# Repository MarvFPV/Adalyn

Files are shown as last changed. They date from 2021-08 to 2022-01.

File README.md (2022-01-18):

# Adalyn

36key QAZ-like handwired keyboard based on the great idea by somepin here on GitHub, check out his repo [here](https://github.com/somepin/qal-handwire)

Currently, the top and bottom are pretty much a friction fit, be aware of that when printing / ordering this case from a fab.

## Required components for handwires

* 36 MX style switches
* 2 2u MX platemount stabs
* 36 Diodes
* a Promicro
* one of ai03's [unified daughterboards](https://github.com/ai03-2725/Unified-Daughterboard)
* a few cables to wire up the matrix
* 4 m3x6mm screws
* 4 m3x8mm countersunk screws 

I personally tend to remove the microUSB connector from the Promicro and solder it directly to a unified daughterboard, that's also why the Promicro cutout may not fit with the USB connector still on the PCB. (I should really write up some documentation on that ^^)

## Required components for the pcb:

- newest pcb based on Atmega32u2

- all necessary components can be found in the bom for jlc/lcsc [here](/PCB/production/smt-assembly) 

## State of PCB:

[Files are ready, prototype not ordered yet]  

- Design moved to an Atmega32u2 as Mcu 

- silkscreen and re-routed, positioned design by [ScatteredDrifter](https://github.com/ScatteredDrifter/Adalyn)

## Render of PCB:

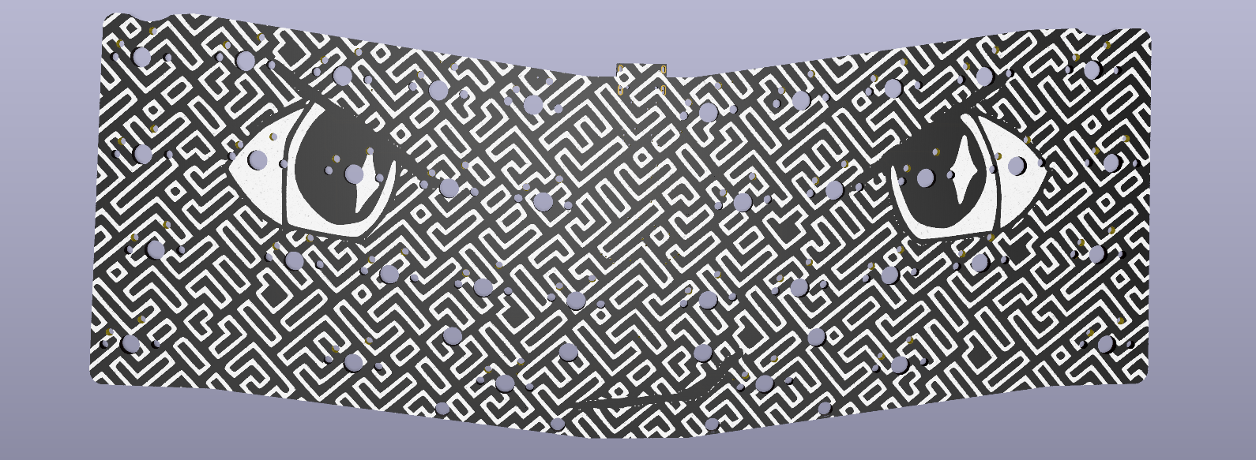
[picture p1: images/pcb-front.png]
frontside


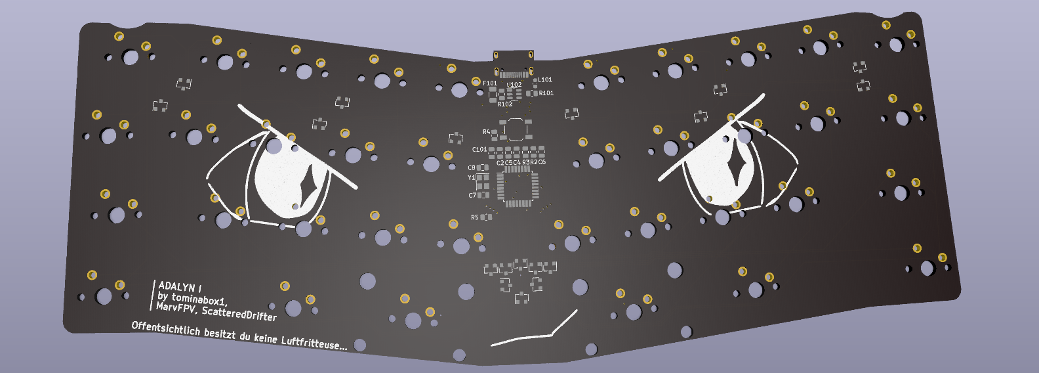
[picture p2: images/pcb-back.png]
backside


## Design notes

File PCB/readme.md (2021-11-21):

# Adalyn PCB
After the development of the handwired Adalyn case, it was clear this great combination needed a formalized pcb. This is that PCB. Designed by tominabox1, the pcb features an ATmega32u4a, USB-C, and ESD protection. The pcb is supported in QMK and VIAL. 

# BOM
The bill of materials is listed below, with LCSC parts where possible. Total unique part count: 14. Total parts: 37. 

| Ref | Qnty | Value | Part | Footprint |
|---|---|---|---|---|
| C1, C2, C4, C101 | 4 | 100nF | C187860  | 0603 |
| C5 | 1 | 10uF | C97885 | 0603 |
| C6 | 1 | 1uF | C302042  | 0603 |
| D101, D102, D103, D104, D105, D106, D107, D108, D109, D110, D111, D112, D113, D114, D115, D116, D117, D118 | 18 | BAV70 | C181110  | SOT-23 |
| F101 | 1 | 700mA | C182438  | 0603 |
| L101 | 1 | 600R@100MHz | C139183  | 0603 |
| R2, R3 | 2 | 22 | C96423 | 0603 |
| R4, R5 | 2 | 10k | C73809 | 0603 |
| R101, R102 | 2 | 5.1k | C415096  | 0603 |
| SW1 | 1 | SW_Push | C589220  | 4.9x4.9 |
| U101 | 1 | ATmega32U4-A | C44854 | TQFP-44_10x10mm_P0.8mm |
| U102 | 1 | PRTR5V0U2X | C2827688 | SOT-143 |
| USB101 | 1 | HRO-TYPE-C-31-M-12 | C165948  | HRO-TYPE-C-31-M-12 |
| Y1 | 1 | 16MHz | C341521  | Crystal:Resonator_SMD_Murata_CSTxExxV-3Pin_3.0x1.1mm_HandSoldering |

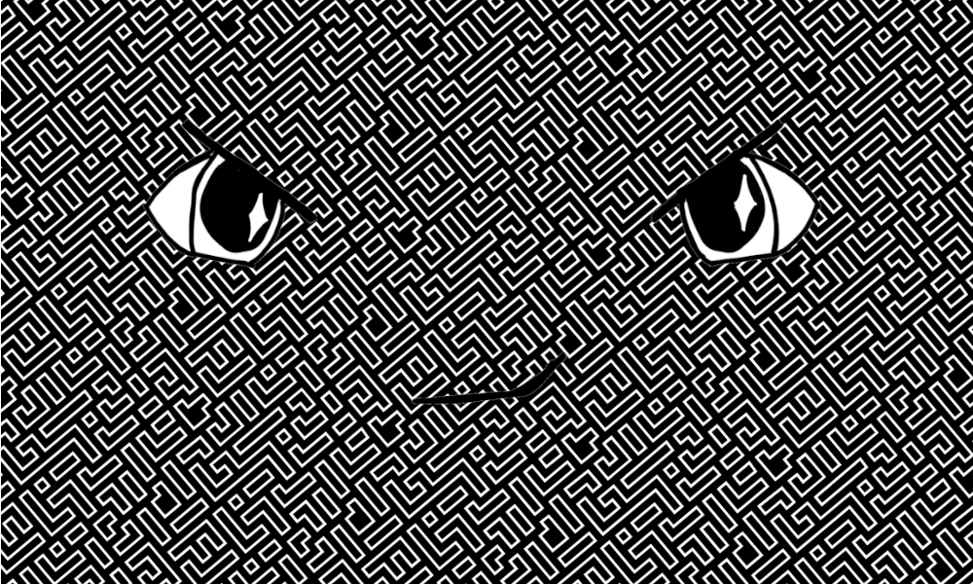
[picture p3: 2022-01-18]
PCB/silkscreen/smirk-pattern-smaller.png

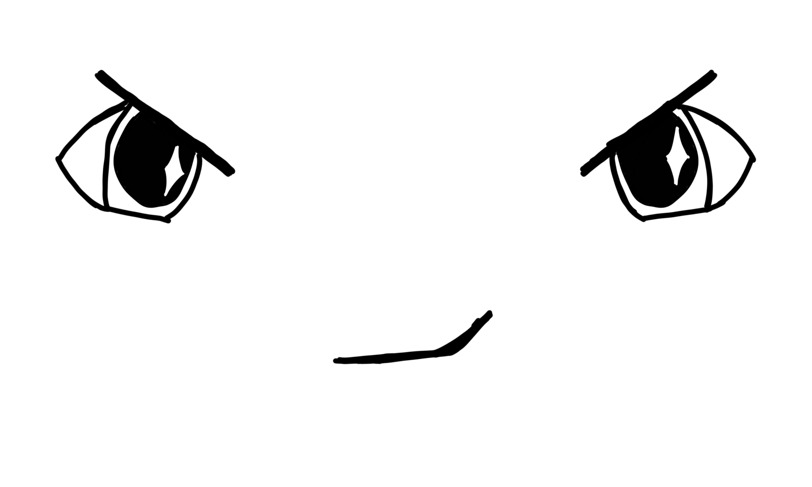
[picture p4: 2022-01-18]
PCB/silkscreen/sketch1642460583686.png

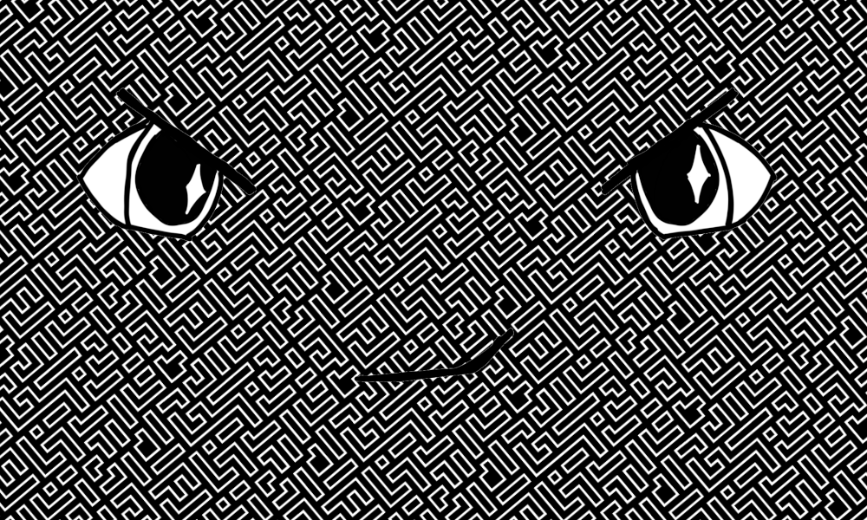
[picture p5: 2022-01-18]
PCB/silkscreen/smirk-pattern-updated.png

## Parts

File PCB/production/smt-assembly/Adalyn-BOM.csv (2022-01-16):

Comment | Designator | Footprint | LCSC
.1uF | C2,C4,C101 | Capacitor_SMD:C_0805_2012Metric | C49678
10uF | C5 | Capacitor_SMD:C_0805_2012Metric | C91245
1uF | C6 | Capacitor_SMD:C_0805_2012Metric | C28323
22pf | C7,C8 | Capacitor_SMD:C_0805_2012Metric | C1804
BAV70 | D101,D102,D103,D104,D105,D106,D107,D108,D109,D110,D111,D112,D113,D114,D115,D116,D117,D118 | Package_TO_SOT_SMD:SOT-23 | C68978
Polyfuse | F101 | Fuse:Fuse_1206_3216Metric | C69688
600R@100MHz | L101 | Inductor_SMD:L_0603_1608Metric
MX-NoLED | MX1,MX2,MX3,MX4,MX5,MX6,MX7,MX8,MX9,MX10,MX11,MX12,MX13,MX15,MX16,MX17,MX18,MX19,MX20,MX21,MX22,MX23,MX24,MX25,MX26,MX27,MX28,MX29,MX30,MX32,MX33,MX34,MX35,MX36,MX37,MX38 | marbastlib-mx:SW_MX_1u
5.1k | R101,R102 | Resistor_SMD:R_0805_2012Metric | C27834
22 | R2,R3 | Resistor_SMD:R_0805_2012Metric | C17561
10k | R4,R5 | Resistor_SMD:R_0805_2012Metric | C17414
SW_Push | SW1 | Keebio-Parts:SW_SPST_TL3342 | C318884
ATmega32U2-AU | U1 | Package_QFP:TQFP-32_7x7mm_P0.8mm | C618733
SRV05-4 | U102 | Package_TO_SOT_SMD:SOT-23-6
HRO-TYPE-C-31-M-12 | USB101 | Type-C:HRO-TYPE-C-31-M-12-Assembly | C165948
Crystal_GND24_Small | Y1 | Crystal:Crystal_SMD_3225-4Pin_3.2x2.5mm | C13738

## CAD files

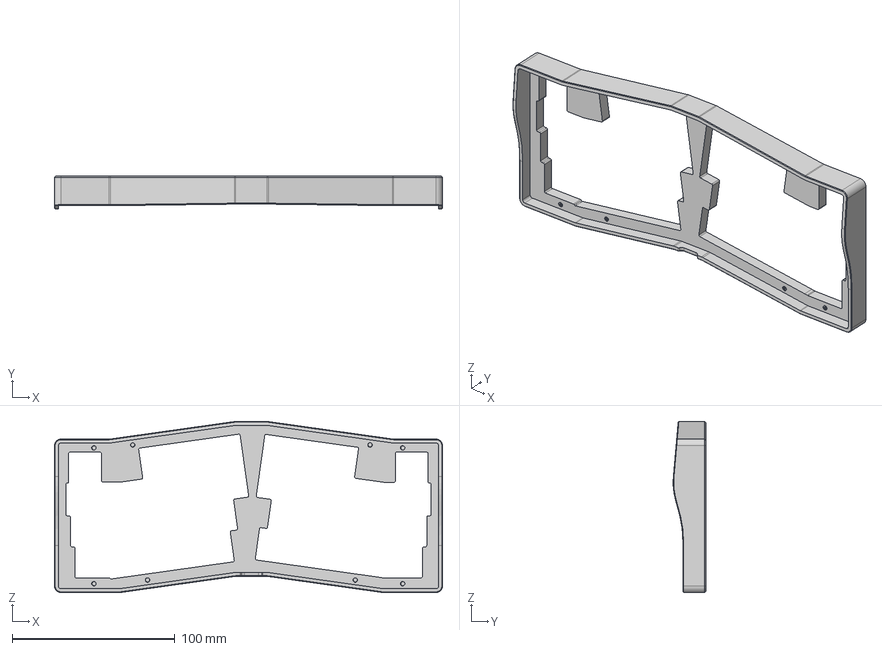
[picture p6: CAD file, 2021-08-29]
STEP/Top.step
238.3 x 20.1 x 105.0 mm

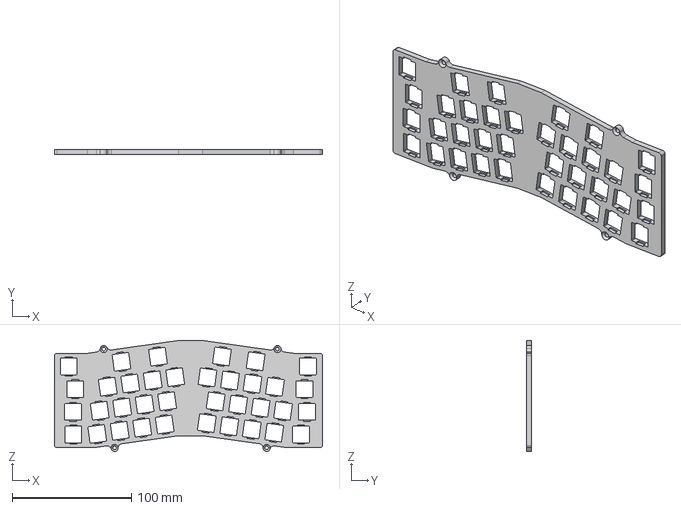
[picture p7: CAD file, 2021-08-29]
STEP/Plate.step
224.8 x 4.00 x 93.1 mm

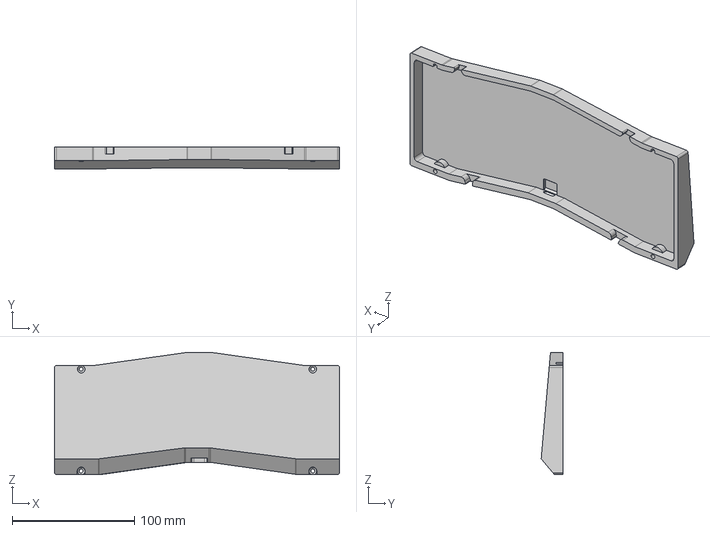
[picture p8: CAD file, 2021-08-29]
STEP/Bottom.step
233.3 x 17.7 x 100.0 mm

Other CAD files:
Adalyn.f3z
STL/Bottom.stl
STL/Plate.stl
STL/Top.stl

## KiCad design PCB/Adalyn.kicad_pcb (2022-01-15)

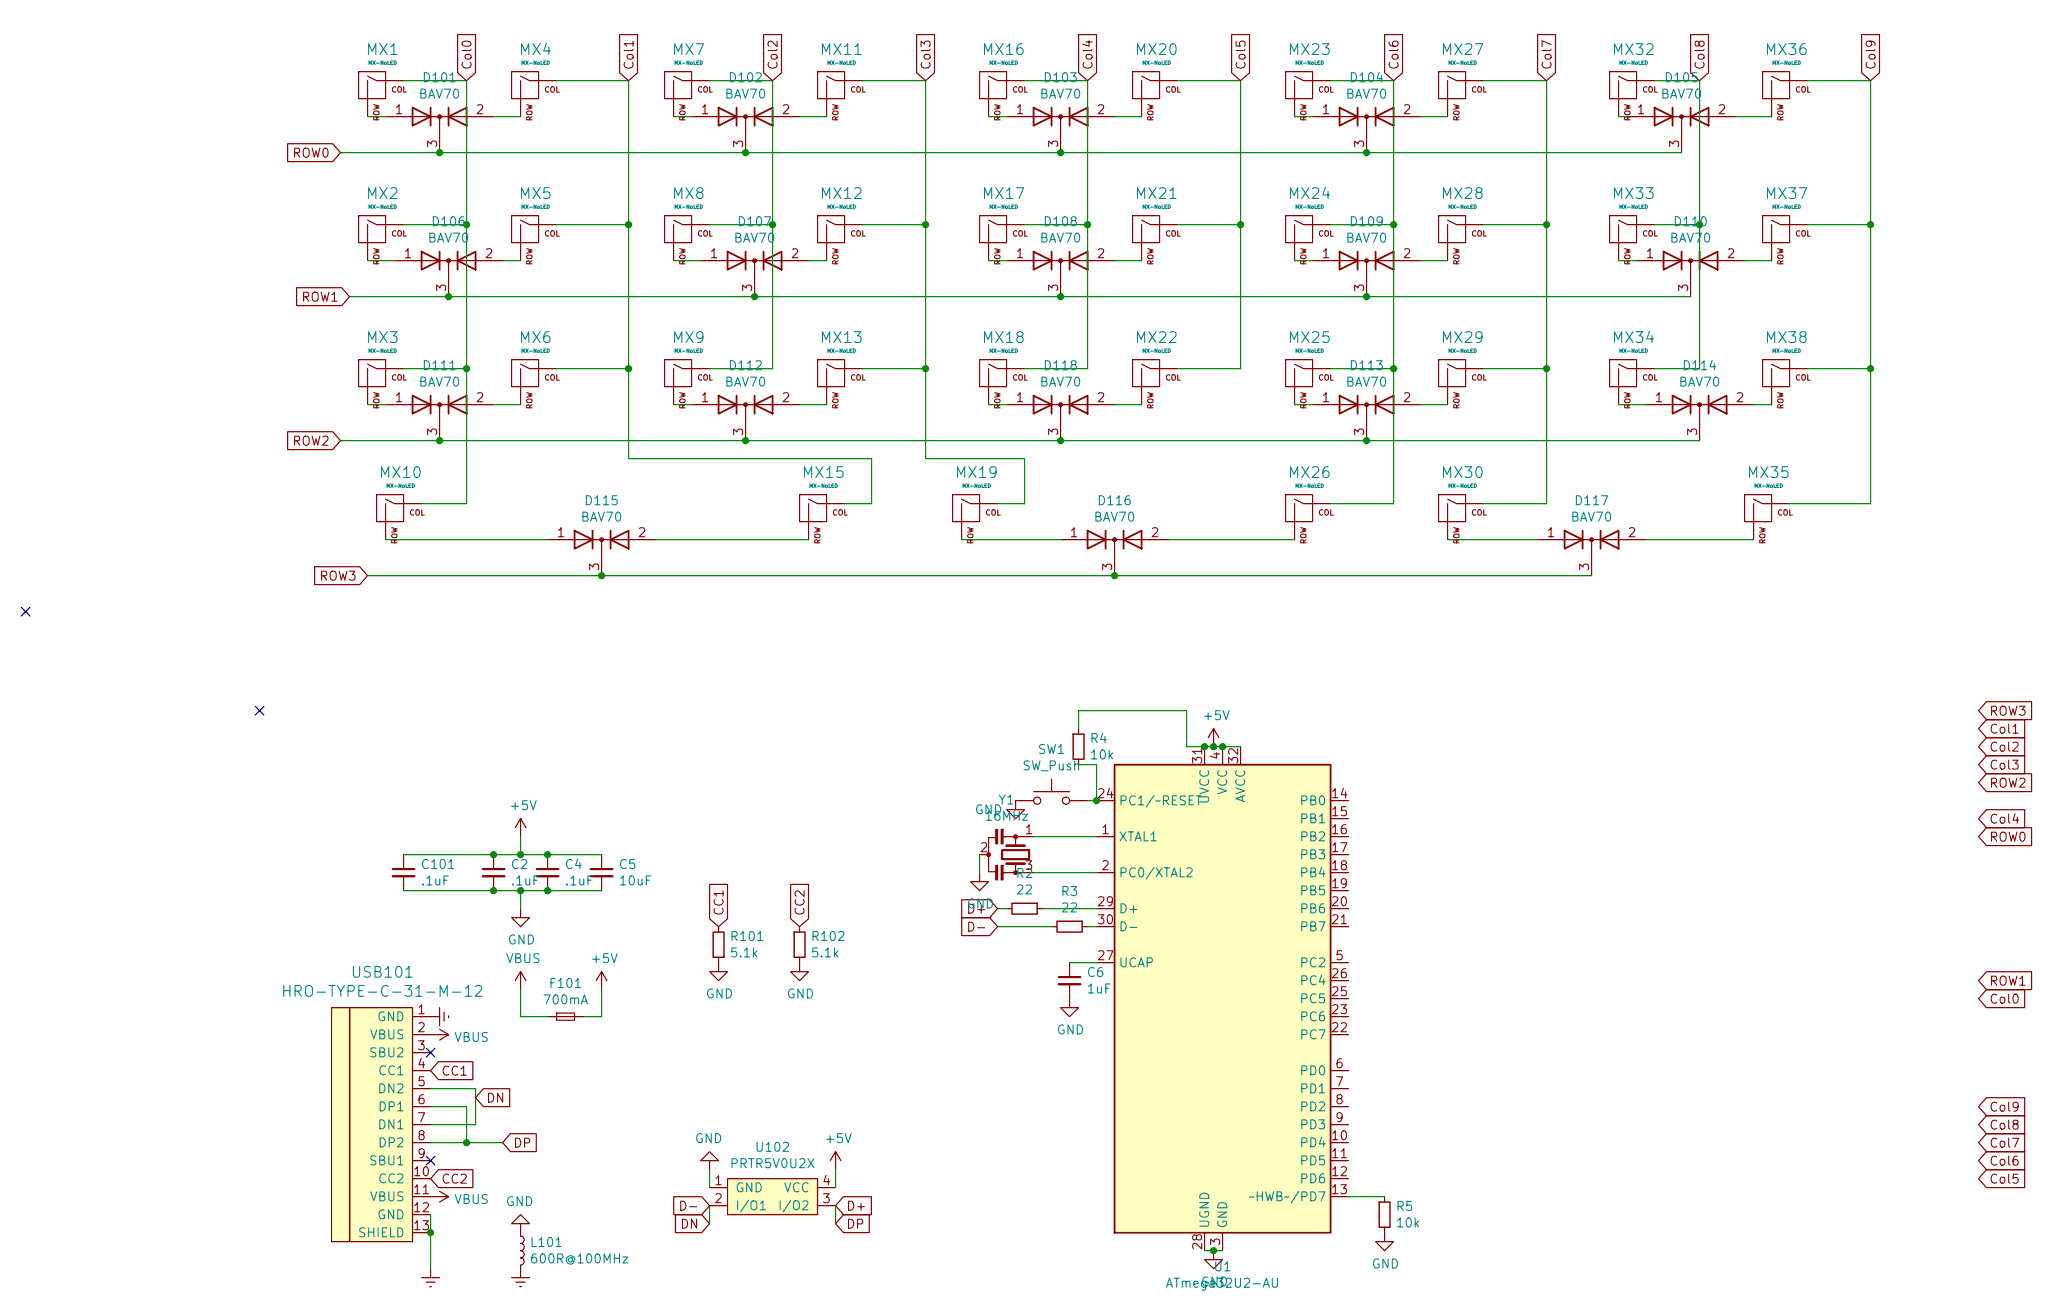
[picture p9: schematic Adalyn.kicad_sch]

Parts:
C2, C4, C101: .1uF; C_0603_1608Metric_Pad1.08x0.95mm_HandSolder
C5: 10uF; C_0603_1608Metric_Pad1.08x0.95mm_HandSolder
C6: 1uF; C_0603_1608Metric_Pad1.08x0.95mm_HandSolder
D101, D102, D103, D104, D105, D106, D107, D108, D109, D110, D111, D112, D113, D114, D115, D116, D117, D118: BAV70; SOT-23
F101: 700mA; Fuse_0603_1608Metric
L101: 600R@100MHz; L_0603_1608Metric
MX1, MX2, MX3, MX4, MX5, MX6, MX7, MX8, MX9, MX10, MX11, MX12, MX13, MX15, MX16, MX17, MX18, MX19, MX20, MX21, MX22, MX23, MX24, MX25, MX26, MX27, MX28, MX29, MX30, MX32, MX33, MX34, MX35, MX36, MX37, MX38: MX-NoLED; MXOnly-1U-NoLED
R2, R3: 22; R_0603_1608Metric_Pad0.98x0.95mm_HandSolder
R4, R5: 10k; R_0603_1608Metric_Pad0.98x0.95mm_HandSolder
R101, R102: 5.1k; R_0603_1608Metric
SW1: SW_Push; SW_SPST_TL3342
U1: ATmega32U2-AU; TQFP-32_7x7mm_P0.8mm
U102: PRTR5V0U2X; SOT-143
USB101: HRO-TYPE-C-31-M-12; HRO-TYPE-C-31-M-12-Assembly
Y1: 16MHz; Resonator_SMD_muRata_CSTxExxV-3Pin_3.0x1.1mm

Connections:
+5V: C2.1, C4.1, C5.1, C101.1, F101.2, R4.1, U1.4 (VCC), U1.31 (UVCC), U1.32 (AVCC), U102.4 (VCC)
CC1: R101.2, USB101.4 (CC1)
CC2: R102.1, USB101.10 (CC2)
Col0: MX1.1 (COL), MX2.1 (COL), MX3.1 (COL), MX10.1 (COL)
Col1: MX4.1 (COL), MX5.1 (COL), MX6.1 (COL), MX15.1 (COL)
Col2: MX7.1 (COL), MX8.1 (COL), MX9.1 (COL)
Col3: MX11.1 (COL), MX12.1 (COL), MX13.1 (COL), MX19.1 (COL)
Col4: MX16.1 (COL), MX17.1 (COL), MX18.1 (COL)
Col5: MX20.1 (COL), MX21.1 (COL), MX22.1 (COL)
Col6: MX23.1 (COL), MX24.1 (COL), MX25.1 (COL), MX26.1 (COL)
Col7: MX27.1 (COL), MX28.1 (COL), MX29.1 (COL), MX30.1 (COL)
Col8: MX32.1 (COL), MX33.1 (COL), MX34.1 (COL)
Col9: MX35.1 (COL), MX36.1 (COL), MX37.1 (COL), MX38.1 (COL)
D+: R2.2, U102.3 (I/O2), USB101.6 (DP1), USB101.8 (DP2)
D-: R3.2, U102.2 (I/O1), USB101.5 (DN2), USB101.7 (DN1)
Earth: L101.2, USB101.1 (GND), USB101.12 (GND), USB101.13 (SHIELD)
GND: C2.2, C4.2, C5.2, C6.2, C101.2, L101.1, R5.2, R101.1, R102.2, SW1.1, U1.3 (GND), U1.28 (UGND), U102.1 (GND), Y1.2
unnamed: C6.1, U1.27 (UCAP)
unnamed: D101.1 (A), MX1.2 (ROW)
unnamed: D101.2 (A), MX4.2 (ROW)
unnamed: D102.1 (A), MX7.2 (ROW)
unnamed: D102.2 (A), MX11.2 (ROW)
unnamed: D103.1 (A), MX16.2 (ROW)
unnamed: D103.2 (A), MX20.2 (ROW)
unnamed: D104.1 (A), MX23.2 (ROW)
unnamed: D104.2 (A), MX27.2 (ROW)
unnamed: D105.1 (A), MX32.2 (ROW)
unnamed: D105.2 (A), MX36.2 (ROW)
unnamed: D106.1 (A), MX2.2 (ROW)
unnamed: D106.2 (A), MX5.2 (ROW)
unnamed: D107.1 (A), MX8.2 (ROW)
unnamed: D107.2 (A), MX12.2 (ROW)
unnamed: D108.1 (A), MX17.2 (ROW)
unnamed: D108.2 (A), MX21.2 (ROW)
unnamed: D109.1 (A), MX24.2 (ROW)
unnamed: D109.2 (A), MX28.2 (ROW)
unnamed: D110.1 (A), MX33.2 (ROW)
unnamed: D110.2 (A), MX37.2 (ROW)
unnamed: D111.1 (A), MX3.2 (ROW)
unnamed: D111.2 (A), MX6.2 (ROW)
unnamed: D112.1 (A), MX9.2 (ROW)
unnamed: D112.2 (A), MX13.2 (ROW)
unnamed: D113.1 (A), MX25.2 (ROW)
unnamed: D113.2 (A), MX29.2 (ROW)
unnamed: D114.1 (A), MX34.2 (ROW)
unnamed: D114.2 (A), MX38.2 (ROW)
unnamed: D115.1 (A), MX10.2 (ROW)
unnamed: D115.2 (A), MX15.2 (ROW)
unnamed: D116.1 (A), MX19.2 (ROW)
unnamed: D116.2 (A), MX26.2 (ROW)
unnamed: D117.1 (A), MX30.2 (ROW)
unnamed: D117.2 (A), MX35.2 (ROW)
unnamed: D118.1 (A), MX18.2 (ROW)
unnamed: D118.2 (A), MX22.2 (ROW)
unnamed: R2.1, U1.29 (D+)
unnamed: R3.1, U1.30 (D-)
unnamed: R4.2, SW1.2, U1.24 (PC1/~RESET)
unnamed: R5.1, U1.13 (~HWB~/PD7)
unnamed: U1.1 (XTAL1), Y1.1
unnamed: U1.2 (PC0/XTAL2), Y1.3
ROW0: D101.3 (K), D102.3 (K), D103.3 (K), D104.3 (K), D105.3 (K)
ROW1: D106.3 (K), D107.3 (K), D108.3 (K), D109.3 (K), D110.3 (K)
ROW2: D111.3 (K), D112.3 (K), D113.3 (K), D114.3 (K), D118.3 (K)
ROW3: D115.3 (K), D116.3 (K), D117.3 (K)
VBUS: F101.1, USB101.2 (VBUS), USB101.11 (VBUS)

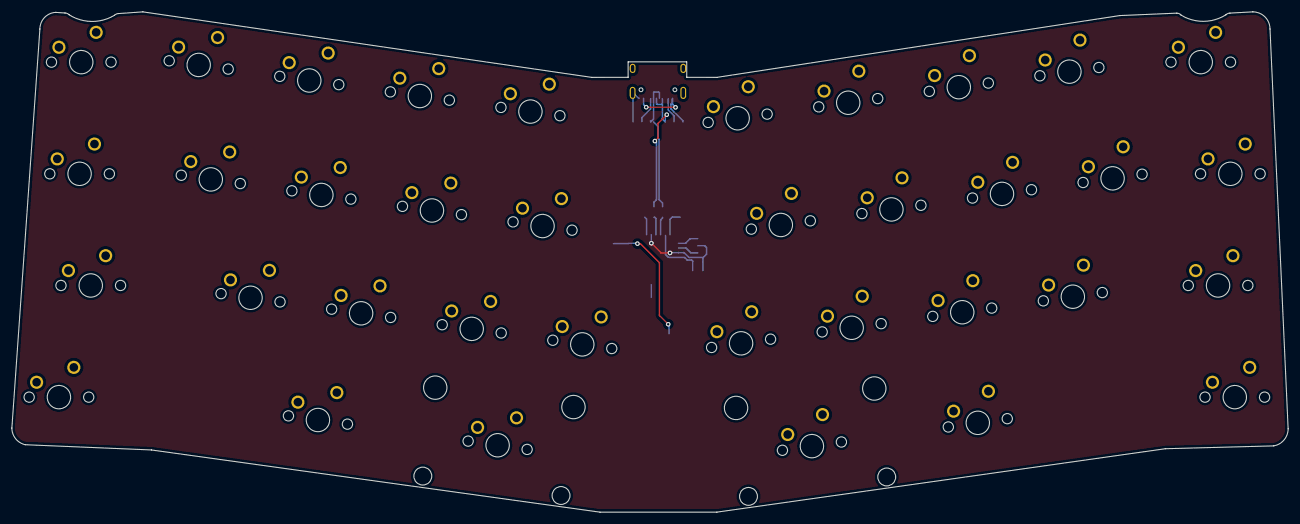
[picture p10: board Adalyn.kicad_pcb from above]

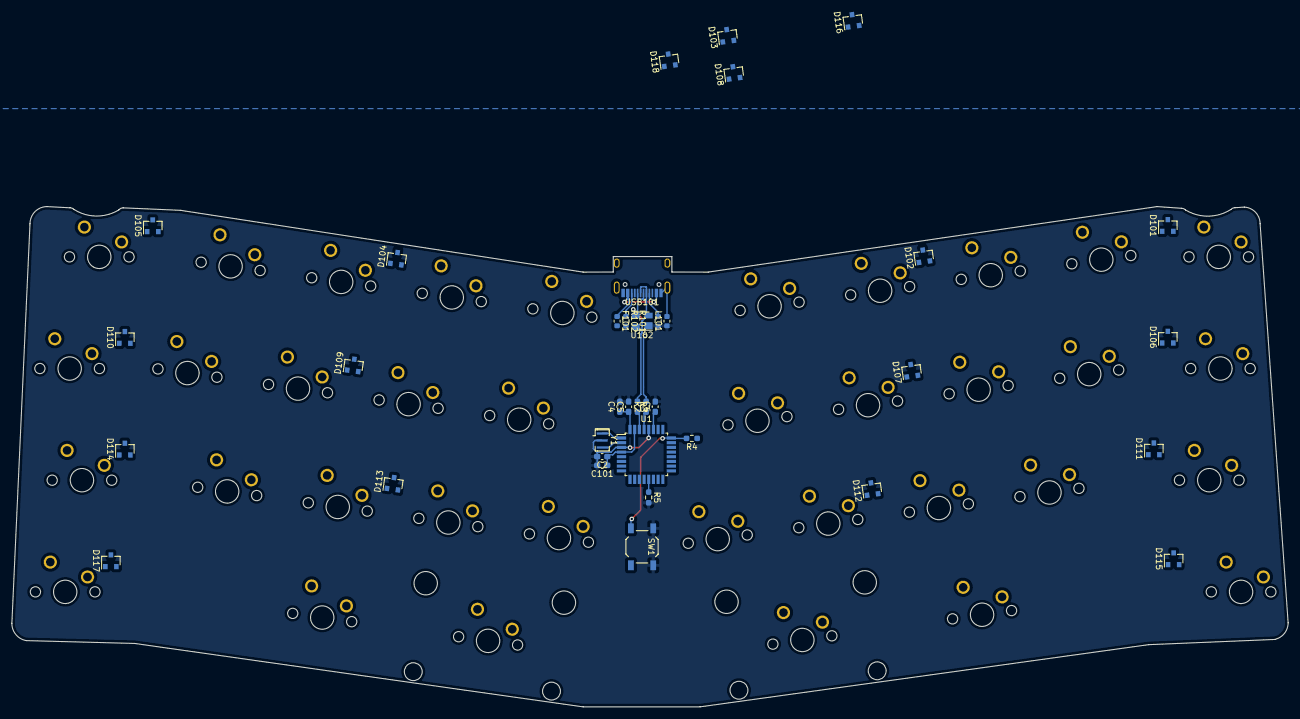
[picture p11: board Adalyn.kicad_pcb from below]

Board: 2 copper layers, 217.7 x 85.3 mm, 72 parts (36 on the bottom side), 65 nets.

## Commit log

2021-07-07 v0.1 upload
    [Adalyn.f3z, Bottom.f3d, Bottom.stl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]
2021-07-08 i am smart
    [Bottom.f3d, Bottom.step, Top.f3d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]
2021-08-29 added pcb version
    [Bottom.step, Bottom.stl, Plate.step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]
2021-11-18 Inital commit of PCB stuff
    [Adalyn-B_Cu.gbr, Adalyn-B_Mask.gbr, Adalyn-B_Paste.gbr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]
2021-11-22 NOT FINSIHED, first commit
    [Adalyn.kicad_pcb, Adalyn.sch]
2021-11-26 update to 5.99
    [Adalyn.kicad_pcb, Adalyn.kicad_sch]
2022-01-16 initial commit: updated bom,pos, finished routing
    [Adalyn-BOM.csv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]
2022-01-17 updated silkscreen and gerber files
    [Adalyn-B_Cu.gbr, Adalyn-B_Mask.gbr, Adalyn-B_Paste.gbr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]
2022-01-18 updated silkscreen
    [Adalyn-B_Cu.gbr, Adalyn-B_Mask.gbr, Adalyn-B_Paste.gbr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]
2022-01-18 finalized board, added updated gerber / bom/pos
    [Adalyn-B_Cu.gbr, Adalyn-B_Mask.gbr, Adalyn-B_Paste.gbr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]
2022-01-18 cleared silkscreen, updated README
    [Adalyn-B_Cu.gbr, Adalyn-B_Mask.gbr, Adalyn-B_Paste.gbr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]
